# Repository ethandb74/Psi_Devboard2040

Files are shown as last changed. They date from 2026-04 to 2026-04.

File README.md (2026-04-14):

# Psi_Devboard2040

A custom built Devboard based of Rasberry-Pi RPI2040 microcontroller. Built with a focus on effeciency and simplicity. Provides as solid tool for future embedded systms project in C/C++ or Python. Very valuble learning experience. The most complex PCB project to date. This project was done as part of a larger electronics and robotics competition #Stasis. 

**This project is named after the greek letter Psi**



ART inspiration: I was inspired by the Greek Mythology, more specificlaly the greek god Poseidon and it formed the theme of this board :)


**Schematic**

Used Rasberry Board as reference




Implemnted new strategies and learned a lot doing this project


**PCB**

Complicated wiring for me. Took a while to puzzle out how to make all connections and get rid of DRC errors but very rewarding process. 




Learned during the PCB desin and routing the most. 

Final






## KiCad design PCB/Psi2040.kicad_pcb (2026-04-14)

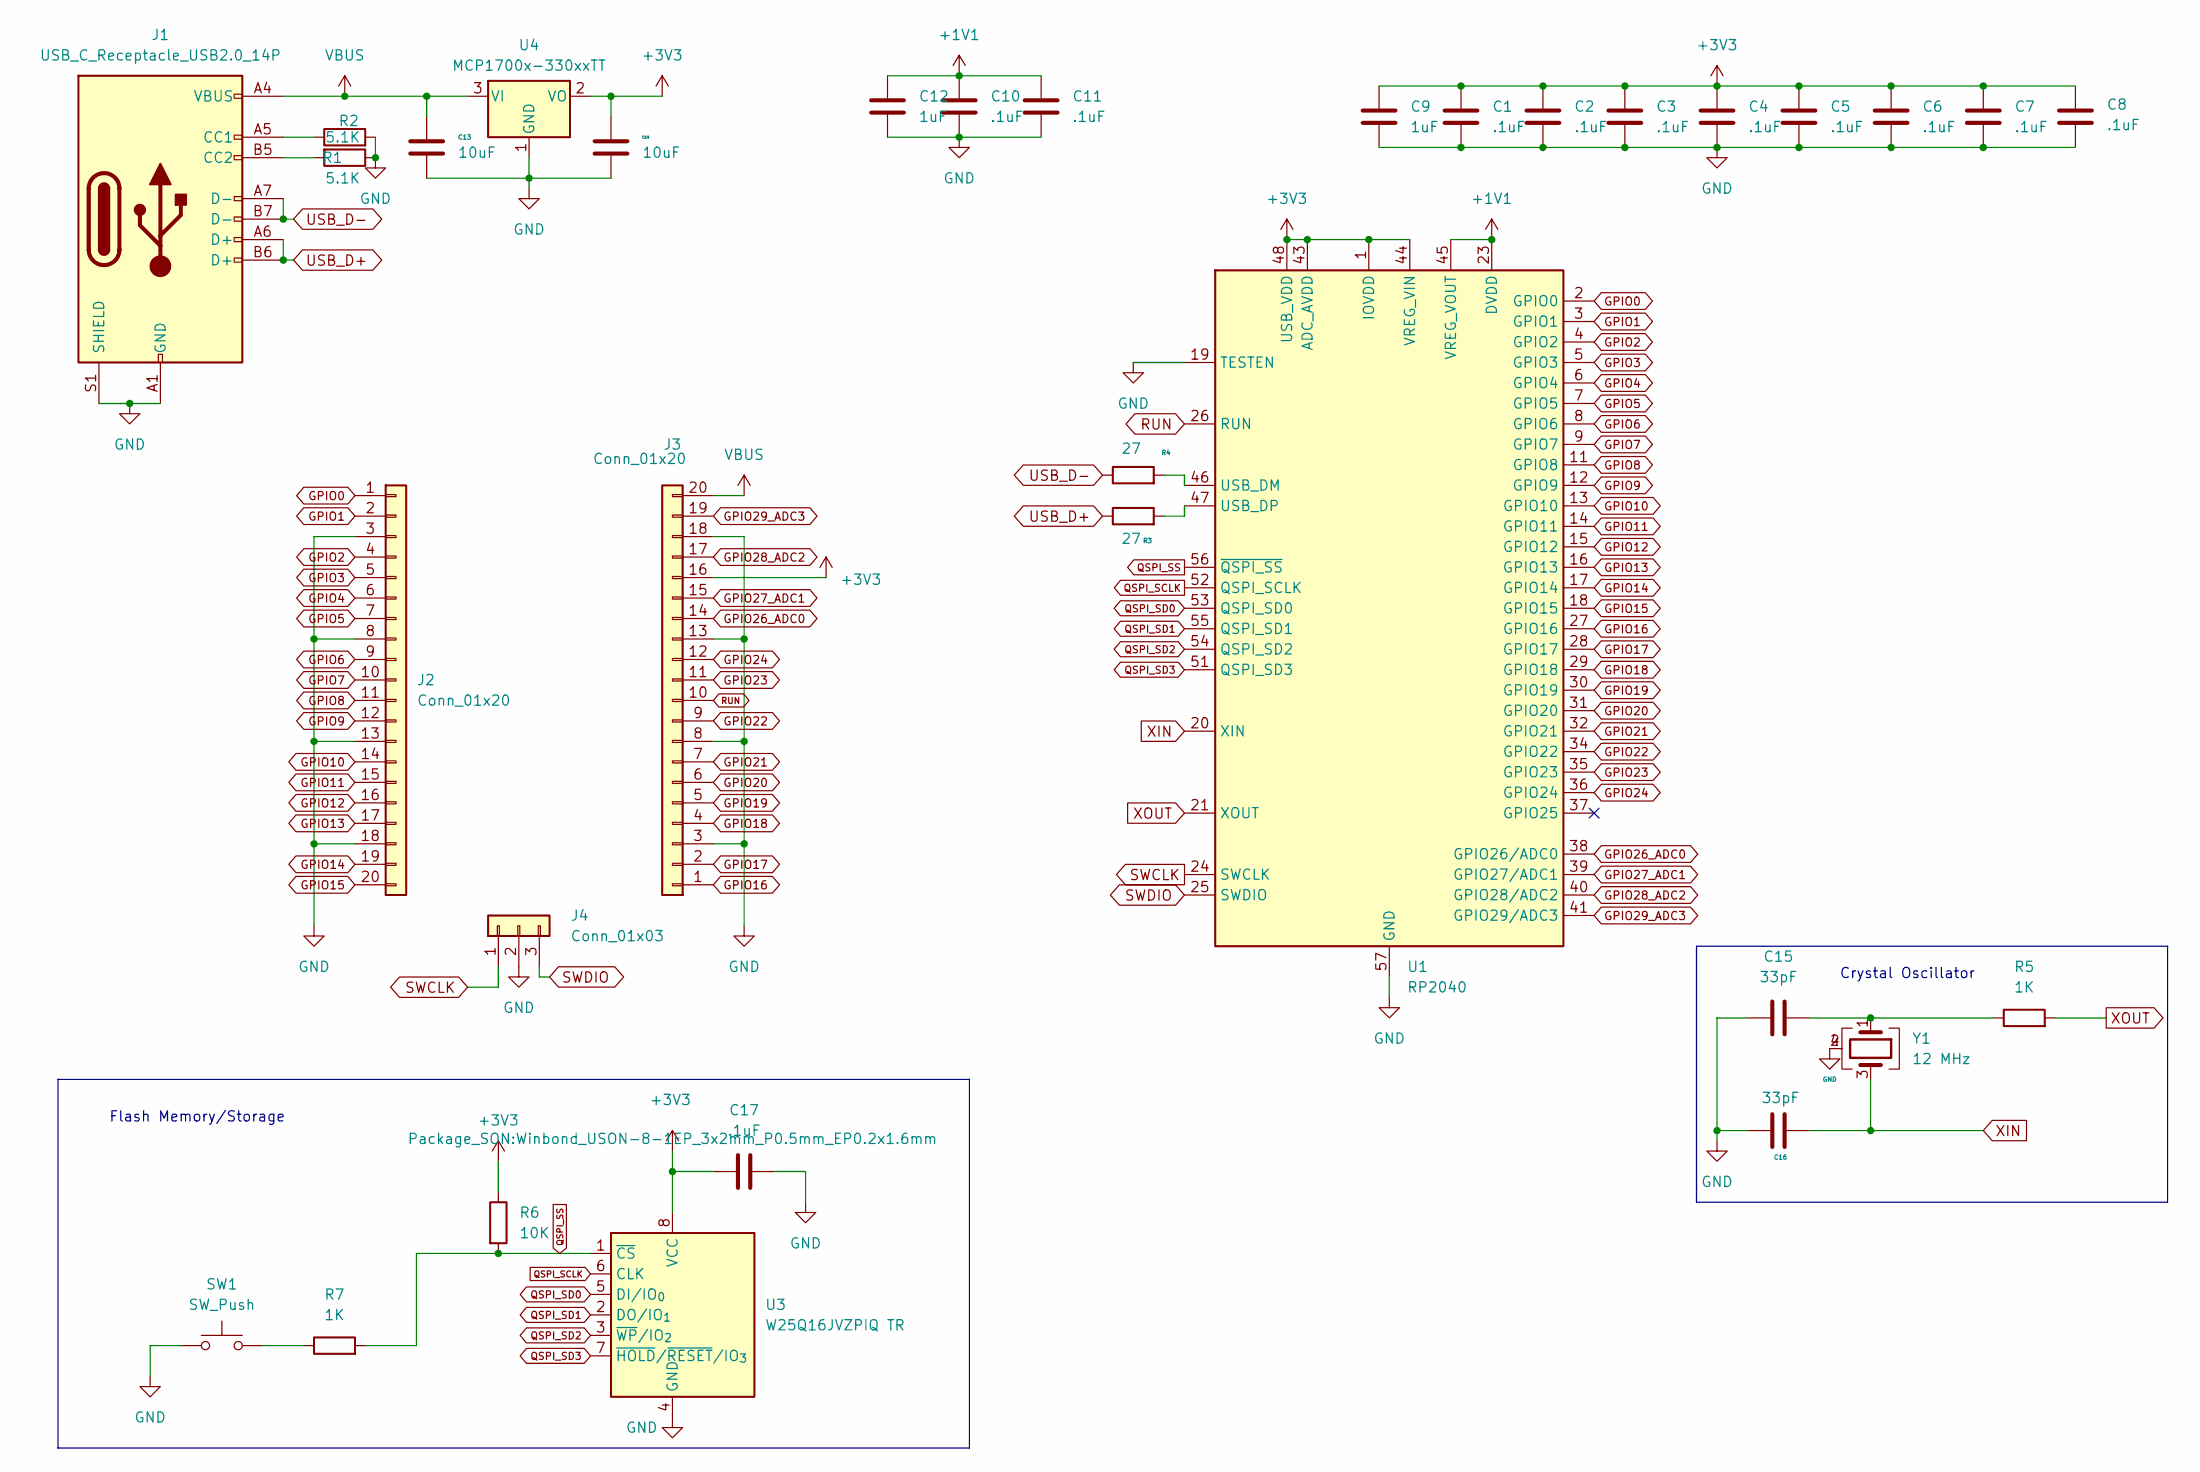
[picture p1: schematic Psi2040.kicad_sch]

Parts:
C1, C2, C3, C4, C5, C6, C7, C8, C10, C11, C17: .1uF; C_0402_1005Metric
C9, C12: 1uF; C_0402_1005Metric
C13, C14: 10uF; C_0402_1005Metric
C15, C16: 33pF; C_0402_1005Metric
J1: USB_C_Receptacle_USB2.0_14P; USB_C_Receptacle_HRO_TYPE-C-31-M-12
J2, J3: Conn_01x20; PinHeader_1x20_P2.54mm_Vertical
J4: Conn_01x03; PinHeader_1x03_P2.54mm_Vertical
R1, R2: 5.1K; R_0402_1005Metric
R3, R4: 27; R_0402_1005Metric
R5, R7: 1K; R_0402_1005Metric
R6: 10K; R_0402_1005Metric
SW1: SW_Push; SW_Push_SPST_NO_Alps_SKRK
U1: RP2040; QFN-56-1EP_7x7mm_P0.4mm_EP3.2x3.2mm
U3: W25Q16JVZPIQ TR; Winbond_USON-8-1EP_3x2mm_P0.5mm_EP0.2x1.6mm
U4: MCP1700x-330xxTT; SOT-23
Y1: 12 MHz; Crystal_SMD_3225-4Pin_3.2x2.5mm

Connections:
+1V1: C10.1, C11.1, C12.1, U1.23 (DVDD), U1.45 (VREG_VOUT), U1.50 (DVDD)
+3V3: C1.1, C2.1, C3.1, C4.1, C5.1, C6.1, C7.1, C8.1, C9.1, C14.1, C17.1, J3.16, R6.1, U1.1 (IOVDD), U1.10 (IOVDD), U1.22 (IOVDD), U1.33 (IOVDD), U1.42 (IOVDD), U1.43 (ADC_AVDD), U1.44 (VREG_VIN), U1.48 (USB_VDD), U1.49 (IOVDD), U3.8 (VCC), U4.2 (VO)
GND: C1.2, C2.2, C3.2, C4.2, C5.2, C6.2, C7.2, C8.2, C9.2, C10.2, C11.2, C12.2, C13.2, C14.2, C15.1, C16.1, C17.2, J1.A1 (GND), J1.A12 (GND), J1.B1 (GND), J1.B12 (GND), J1.S1 (SHIELD), J2.3, J2.8, J2.13, J2.18, J3.3, J3.8, J3.13, J3.18, J4.2, R1.1, R2.2, SW1.1, U1.19 (TESTEN), U1.57 (GND), U3.4 (GND), U4.1 (GND), Y1.2 (G), Y1.4 (G)
GPIO0: J2.1, U1.2 (GPIO0)
GPIO1: J2.2, U1.3 (GPIO1)
GPIO2: J2.4, U1.4 (GPIO2)
GPIO3: J2.5, U1.5 (GPIO3)
GPIO4: J2.6, U1.6 (GPIO4)
GPIO5: J2.7, U1.7 (GPIO5)
GPIO6: J2.9, U1.8 (GPIO6)
GPIO7: J2.10, U1.9 (GPIO7)
GPIO8: J2.11, U1.11 (GPIO8)
GPIO9: J2.12, U1.12 (GPIO9)
GPIO10: J2.14, U1.13 (GPIO10)
GPIO11: J2.15, U1.14 (GPIO11)
GPIO12: J2.16, U1.15 (GPIO12)
GPIO13: J2.17, U1.16 (GPIO13)
GPIO14: J2.19, U1.17 (GPIO14)
GPIO15: J2.20, U1.18 (GPIO15)
GPIO16: J3.1, U1.27 (GPIO16)
GPIO17: J3.2, U1.28 (GPIO17)
GPIO18: J3.4, U1.29 (GPIO18)
GPIO19: J3.5, U1.30 (GPIO19)
GPIO20: J3.6, U1.31 (GPIO20)
GPIO21: J3.7, U1.32 (GPIO21)
GPIO22: J3.9, U1.34 (GPIO22)
GPIO23: J3.11, U1.35 (GPIO23)
GPIO24: J3.12, U1.36 (GPIO24)
GPIO26_ADC0: J3.14, U1.38 (GPIO26/ADC0)
GPIO27_ADC1: J3.15, U1.39 (GPIO27/ADC1)
GPIO28_ADC2: J3.17, U1.40 (GPIO28/ADC2)
GPIO29_ADC3: J3.19, U1.41 (GPIO29/ADC3)
unnamed 32: C15.2, R5.1, Y1.1; also elsewhere on the board
unnamed: J1.A5 (CC1), R2.1
unnamed: J1.B5 (CC2), R1.2
unnamed: R7.1, SW1.2
unnamed: R4.2, U1.46 (USB_DM)
unnamed: R3.2, U1.47 (USB_DP)
QSPI_SCLK: U1.52 (QSPI_SCLK), U3.6 (CLK)
QSPI_SD0: U1.53 (QSPI_SD0), U3.5 (DI/IO_{0})
QSPI_SD1: U1.55 (QSPI_SD1), U3.2 (DO/IO_{1})
QSPI_SD2: U1.54 (QSPI_SD2), U3.3 (~WP/IO_{2})
QSPI_SD3: U1.51 (QSPI_SD3), U3.7 (~HOLD/~RESET/IO_{3})
QSPI_SS: R6.2, R7.2, U1.56 (~QSPI_SS), U3.1 (~CS)
RUN: J3.10, U1.26 (RUN)
SWCLK: J4.1, U1.24 (SWCLK)
SWDIO: J4.3, U1.25 (SWDIO)
USB_D+: J1.A6 (D+), J1.B6 (D+), R3.1
USB_D-: J1.A7 (D-), J1.B7 (D-), R4.1
VBUS: C13.1, J1.A4 (VBUS), J1.A9 (VBUS), J1.B4 (VBUS), J1.B9 (VBUS), J3.20, U4.3 (VI)
XIN: C16.2, U1.20 (XIN), Y1.3
XOUT: R5.2, U1.21 (XOUT); also elsewhere on the board

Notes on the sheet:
Flash Memory/Storage
Crystal Oscillator

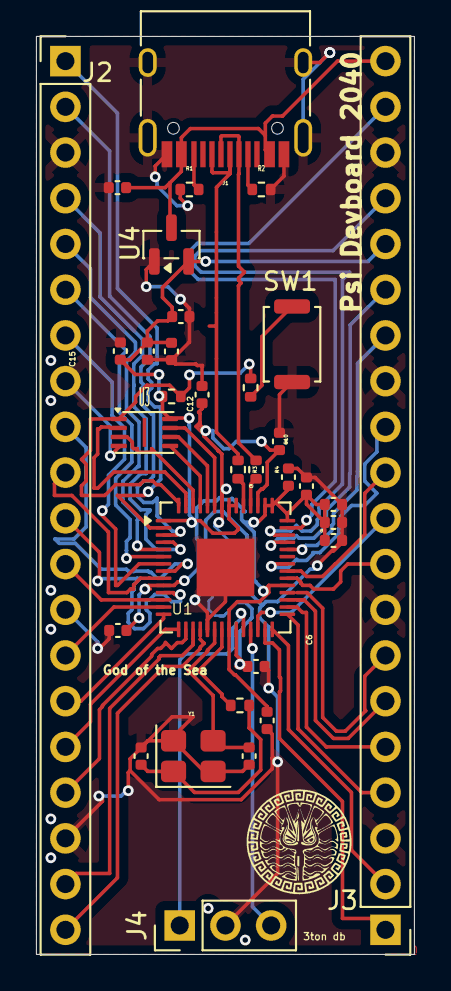
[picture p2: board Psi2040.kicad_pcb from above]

Board: 2 copper layers, 21.0 x 51.0 mm, 34 parts (0 on the bottom side), 52 nets.

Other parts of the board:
3ton db: 1K; R_0402_1005Metric
Psi Devboard 2040: God of the Sea; psiimage

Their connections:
unnamed 32: 3ton db.1; also elsewhere on the board
XOUT: 3ton db.2; also elsewhere on the board
